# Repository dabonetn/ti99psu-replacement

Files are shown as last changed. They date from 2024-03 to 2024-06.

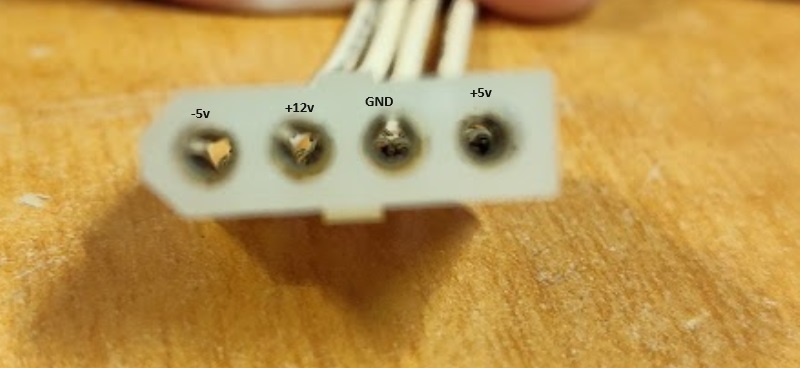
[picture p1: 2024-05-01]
Pics/EarlyPSU Female Connector.jpg

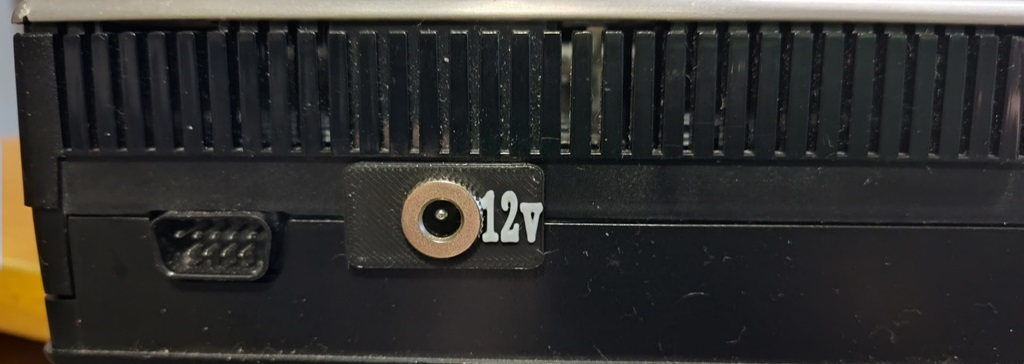
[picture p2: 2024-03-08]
Pics/Rear Jack.jpg

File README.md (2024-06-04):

# ti99psu-replacement
Full drop in TI99/4a Power supply replacement. No soldering.

This board is a drop in replacement for the internal TI99/4a power board that uses the pin headers to connect to the motherboard.
There is a header to install the pigtail that some early units used.

It uses a regulated +12V DC external power supply, 48 watt or greater. (4amp)

Use a good quality supply, as this is the actual +12v for the computer.

This uses a DFR0831 5v buck converter, that's rated for +5v@4a, but I recommned no more than 3.5a draw.

There's a error on the schematics, the 220ohm resistor isn't enough for modern leds, so I recommend a 560ohm for bright or 2.2k for dull.

You should also use a 2.5mm thermal pad underneath the DFR8031 to help cool it.

-5v is provided with a P78E05-1000 switching regulator...This is rated for 1amp compared to the originals .5 amp.
-5v is basically there for the 4116 ram.

The SUP53P06-20-E3 mosfet is there for reverse voltage input, but you can leave it out by connecting pins d & s ( the two close to the edge of the board)

This is a remix of the TI99-4A-dc-power-board by jonn-reenthused

https://github.com/jonn-reenthused/TI99-4A-dc-power-board

I wanted more than a 2a 5v supply, so I spun this up. 

This project was made using EasyEDA, because the original version I forked this from was.
I'll eventually move it to kicad.

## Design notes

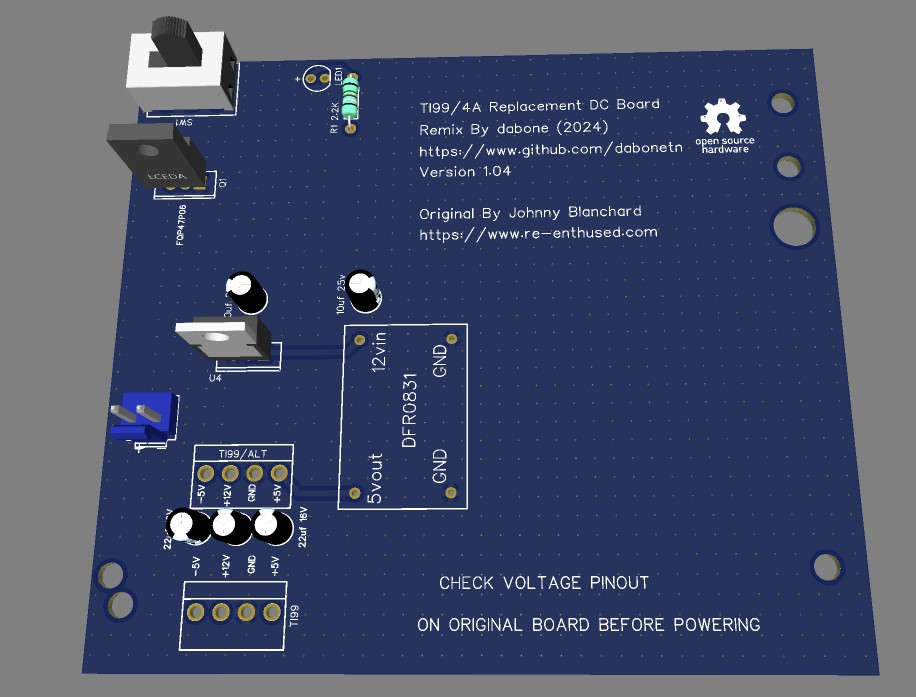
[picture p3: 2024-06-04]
3dView.JPG

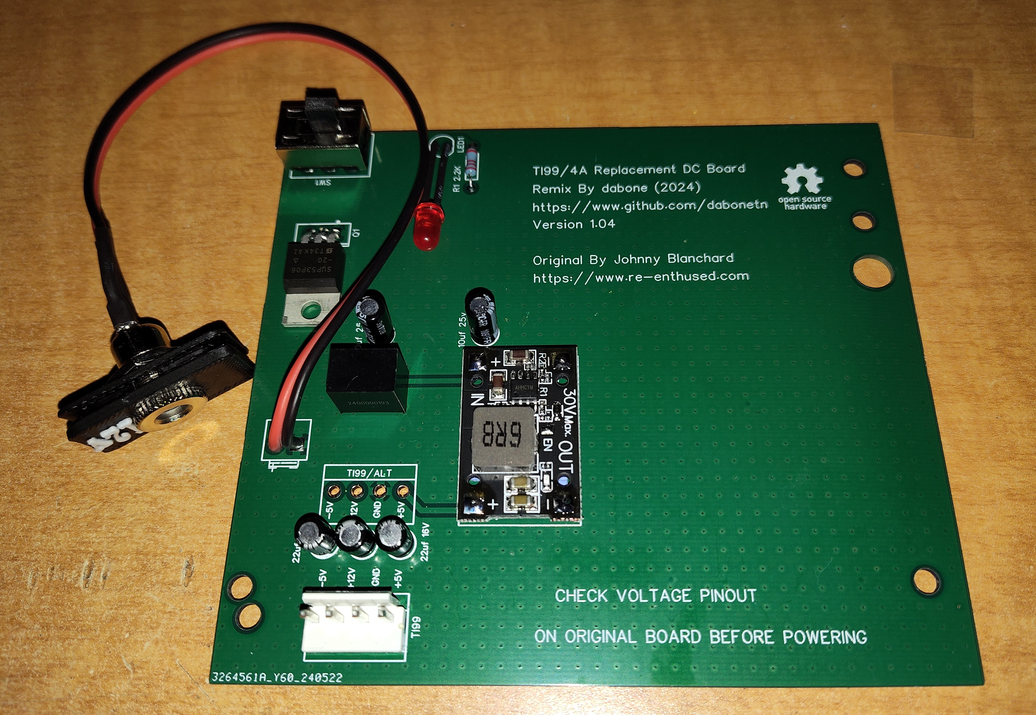
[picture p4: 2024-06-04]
Pics/Version 1.04.jpg

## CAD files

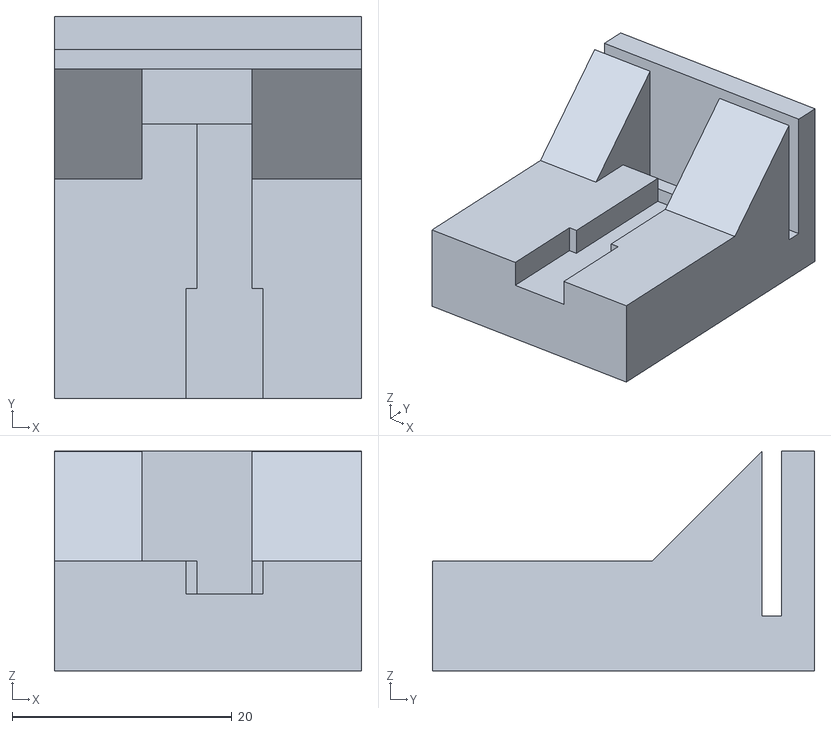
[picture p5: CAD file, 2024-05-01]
STL/Shipping Clip for LED.stl
28.0 x 34.8 x 20.0

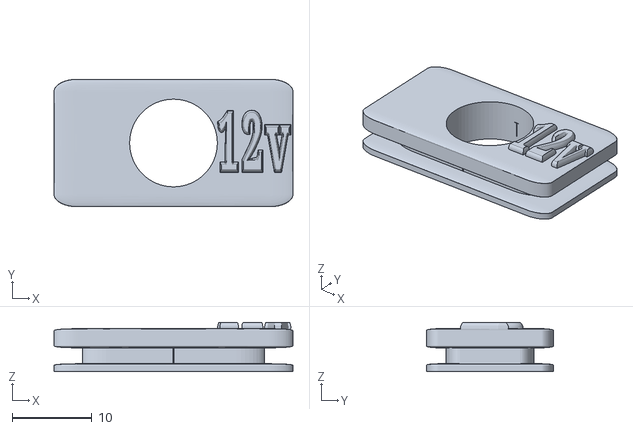
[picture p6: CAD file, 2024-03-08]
STL/TI99 4a Power Jack Cover.stl
30.0 x 16.0 x 6.20

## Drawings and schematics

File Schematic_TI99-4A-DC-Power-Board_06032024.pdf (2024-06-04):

+12V

+5V

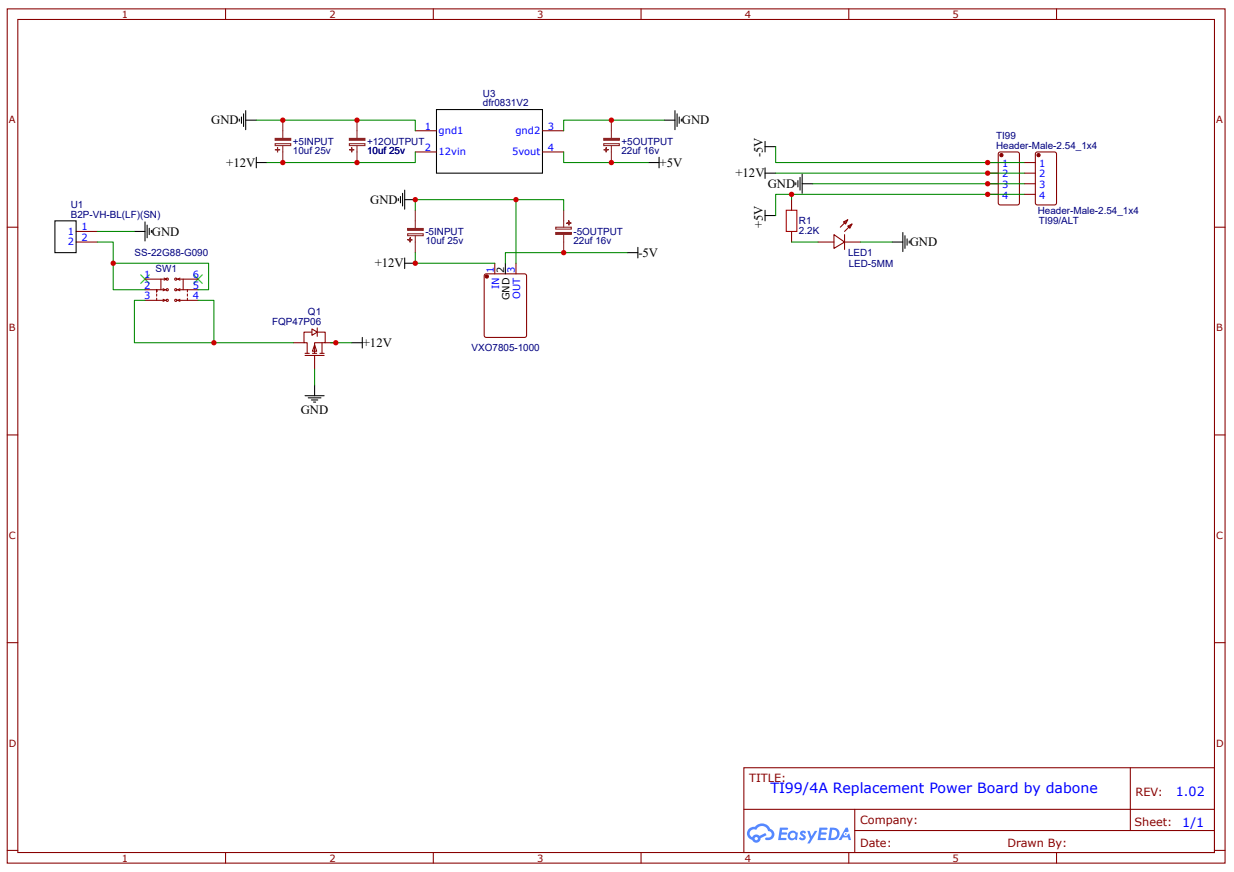
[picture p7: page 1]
TITLE:; TI99/4A Replacement Power Board by dabone; REV: 1.02; Date:; Sheet: 1/1; Drawn By:; Company:; Header-Male-2.54_1x4; LED-5MM; LED1; +5INPUT; -5OUTPUT; -5INPUT; dfr0831V2; gnd1; 12vin 2; gnd2; 5vout 4; GND; VXO7805-1000; OUT; +12OUTPUT; +5OUTPUT; FQP47P06; Header-Male-2.54_1x4 TI99/ALT

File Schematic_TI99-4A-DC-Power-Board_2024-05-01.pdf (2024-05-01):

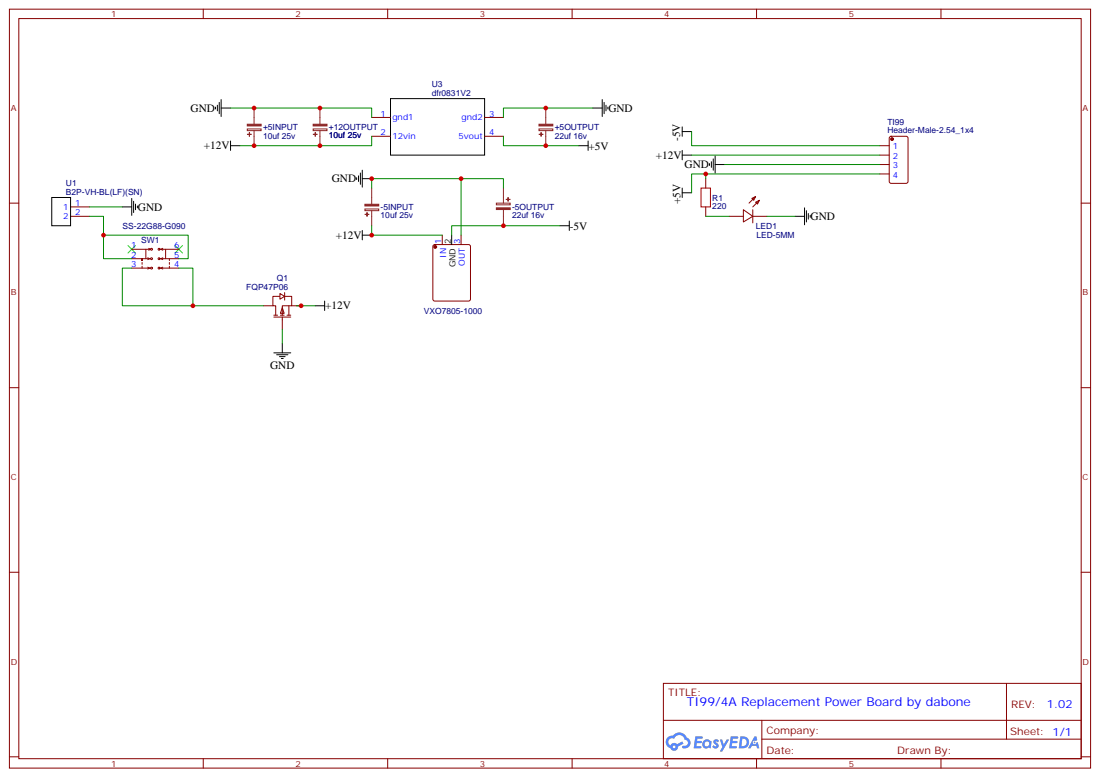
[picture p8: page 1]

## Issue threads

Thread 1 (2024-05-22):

Question for board thickness

AxelAhlborn, 2024-05-22:
Hi!

What thickness should the board have?

Greetings Axel

dabonetn, 2024-06-21:
I always use the default 1.6mm, feel free to experiment.

Closed 2024-06-21.

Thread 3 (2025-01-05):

-5v converter

shift838, 2025-01-05:
having an issue finding a active -5v DC to DC converter that is higher than -300ma power output.  The one that you reference (P78E05-1000) for the -5v version only goes up to -500ma.  Will -300ma suffice since the normal negative ma draw on a standard 4A is -300ma anyway?

dabonetn, 2025-01-05:
Last ones I used were the YLPTEC K7805-1000R.

I've also used the CUI P7805-Q24-S5-S.

But I'm guessing the 300ma would be fine, since it matches the original output limit.

Looking around the schematics, -5 is used on the 4116 Drams, Groms, and reset circuit.

dabonetn, 2025-01-05:
And it appears the new R-78CK5.0-0.5 is a 500ma that supports -5v output.

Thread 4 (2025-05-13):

Provide a BOM?

keronian, 2025-05-13:
Any way you could put together a basic BOM for this?  A lot of the parts are easy enough to figure out, but a few are a bit tricky, like the switch, the DC barrel adapter you used that fits your 3d print...

It would just be nice to have the full list.

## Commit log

2024-03-08 Initial commit.
    [TI99 4a Power Jack Cover.stl]
2024-03-08 Create Dirs
    [TI99 4a Power Jack Cover.stl]
2024-05-01 Update to Board Version 1.03
    Had to replace the original switch, because Easyeda decided to change the part footprint.. grrrr.
    [Shipping Clip for LED.stl]
